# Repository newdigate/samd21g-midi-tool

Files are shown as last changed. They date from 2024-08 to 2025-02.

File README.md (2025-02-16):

# Midi Tool
[kicad](https://www.kicad.org/) design files for a general purpose midi dev board based on Arduino MKRZero 

* [samdg21](https://www.microchip.com/en-us/product/atsamd21g18) arm cortex m0 microcontroller
* DIN-5 midi input and output
* st7735 display (128x128 16bit)
* [PCF8523T](https://www.nxp.com/part/PCF8523T) realtime clock RTC
* socket for micro-SD card
* status LED
* SWD connection for programming
* PJ-320A connector for 2 foot-switches
* 5V POWER via USB
* 3V3 regulator
* 4-pin socket for neopixel strip
* Status LED

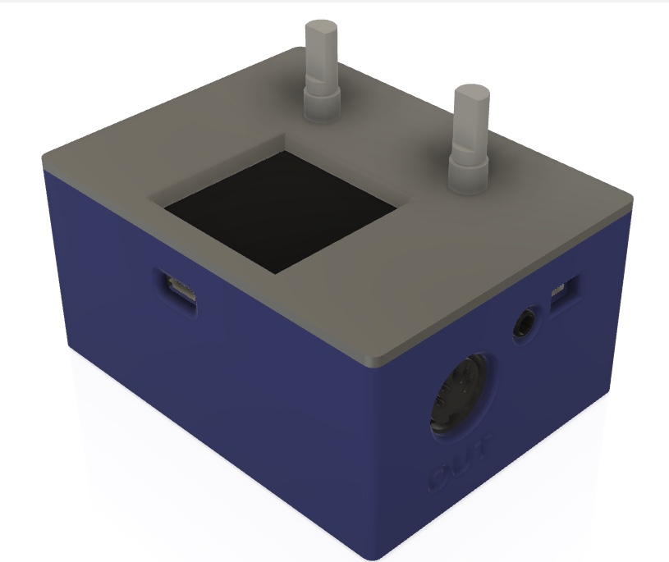
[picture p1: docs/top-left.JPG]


## Firmware
 * [samd21g-midi-tool-software](https://github.com/newdigate/samd21g-midi-tool-software)
   
## Kicad plugins
 * [JLCPCB](https://github.com/Bouni/kicad-jlcpcb-tools)
 * [Freerouting](https://github.com/freerouting/freerouting)

## Arduino libraries
* [PCF8523](https://github.com/SpellFoundry/PCF8523)
* [Adafruit-ST7735-Library](https://github.com/adafruit/Adafruit-ST7735-Library)
* [arduino_midi_library](https://github.com/FortySevenEffects/arduino_midi_library)

## sources / credits:
  * schematics and pcb design based on [MKRZERO Arduino](https://docs.arduino.cc/hardware/mkr-zero/)   
  * 3d models:
    * [PJ320A PJ320D 3.5mm JACK](https://grabcad.com/library/pj320a-pj320d-3-5mm-jack-1)
    * [SMD CR1220 Battery case](https://grabcad.com/library/smd-cr1220-battery-case-1)
  * footprints
    * [PJ-320A](https://github.com/nathanhborger/PJ-320A_KiCad_Library)

## images
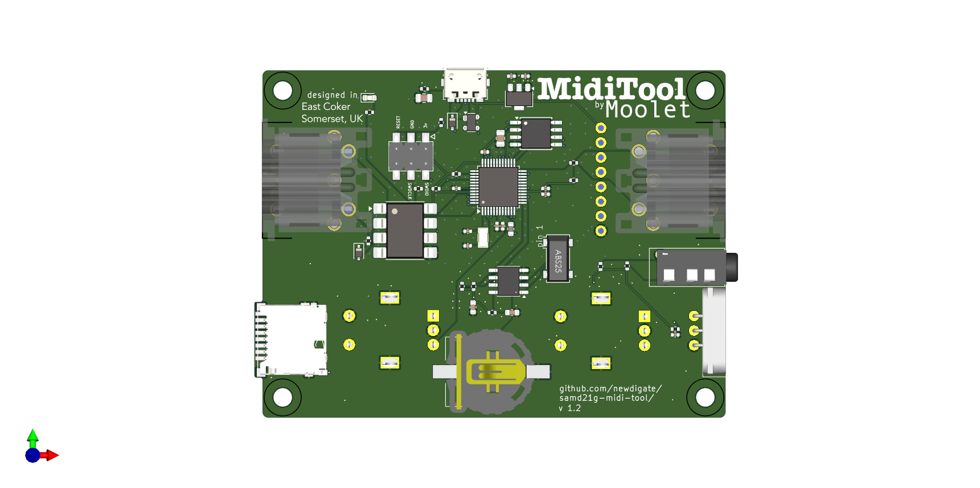
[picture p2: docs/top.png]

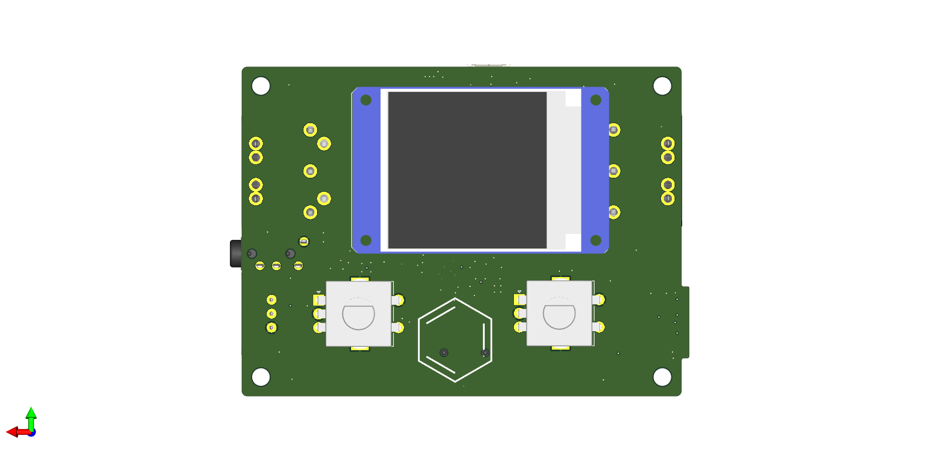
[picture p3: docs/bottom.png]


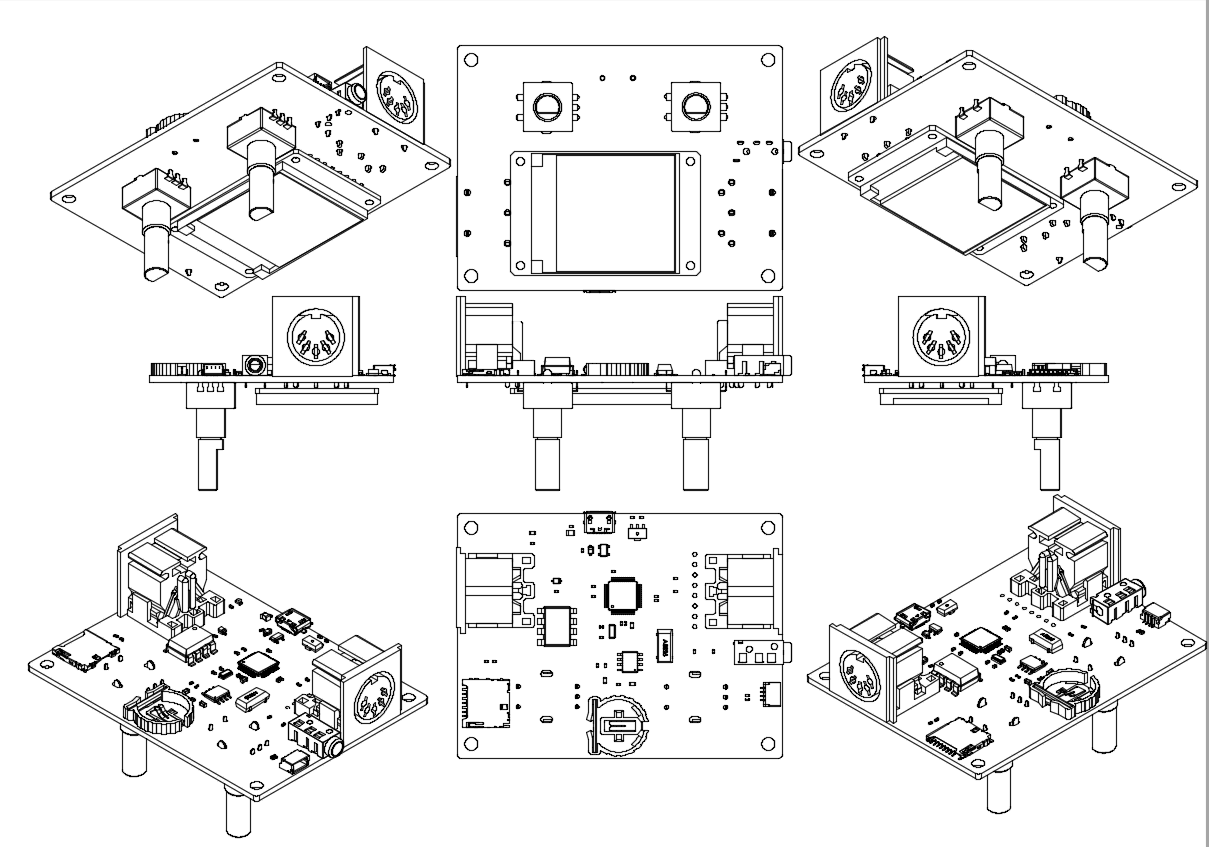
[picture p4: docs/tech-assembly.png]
tech-assembly


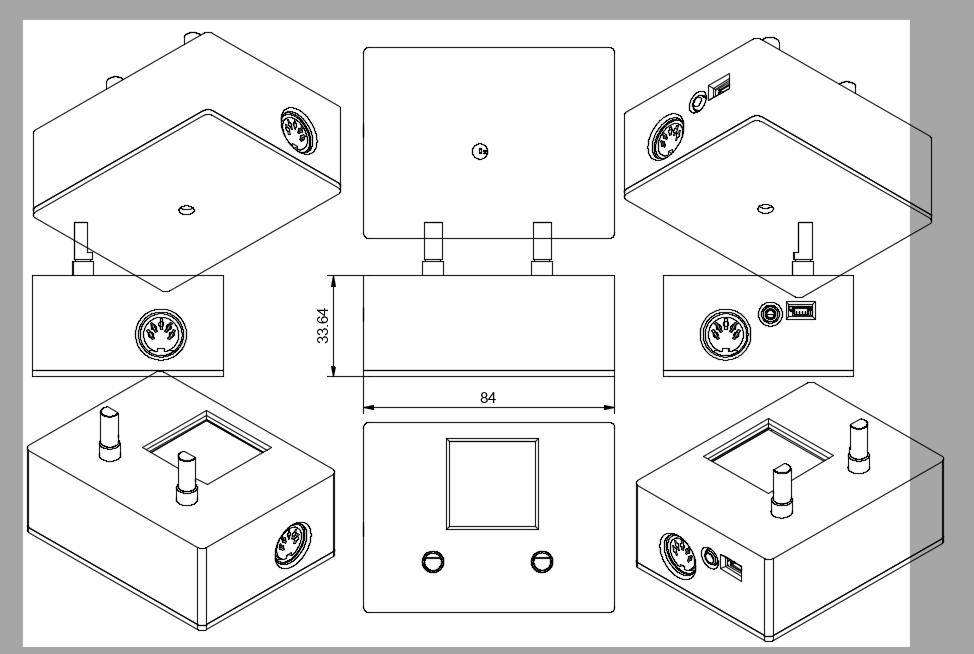
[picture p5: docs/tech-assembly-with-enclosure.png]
tech-assembly-with-enclosure


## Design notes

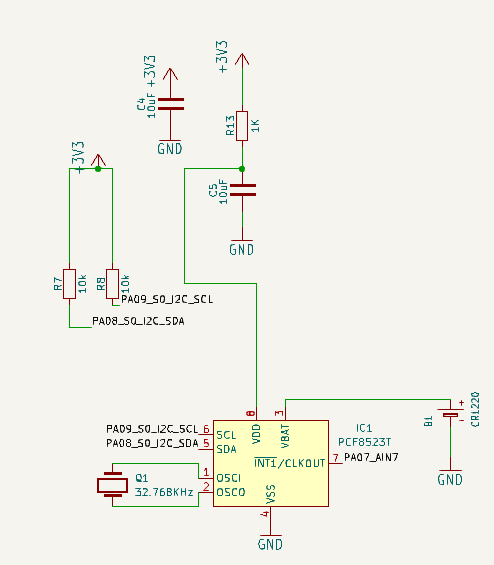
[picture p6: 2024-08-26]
docs/schematic2.png

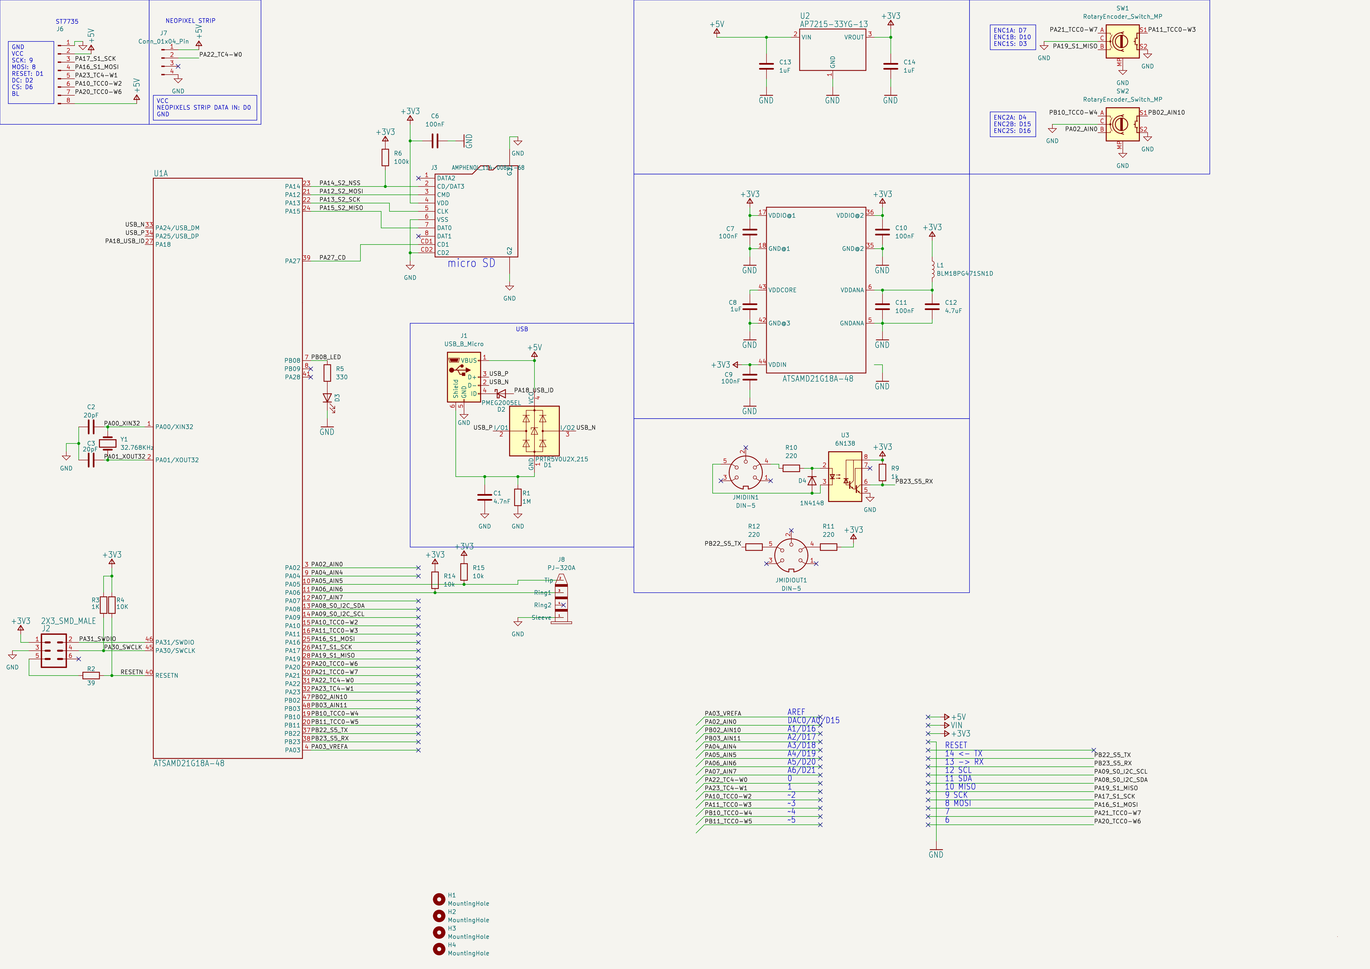
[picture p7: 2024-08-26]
docs/schematic1.png

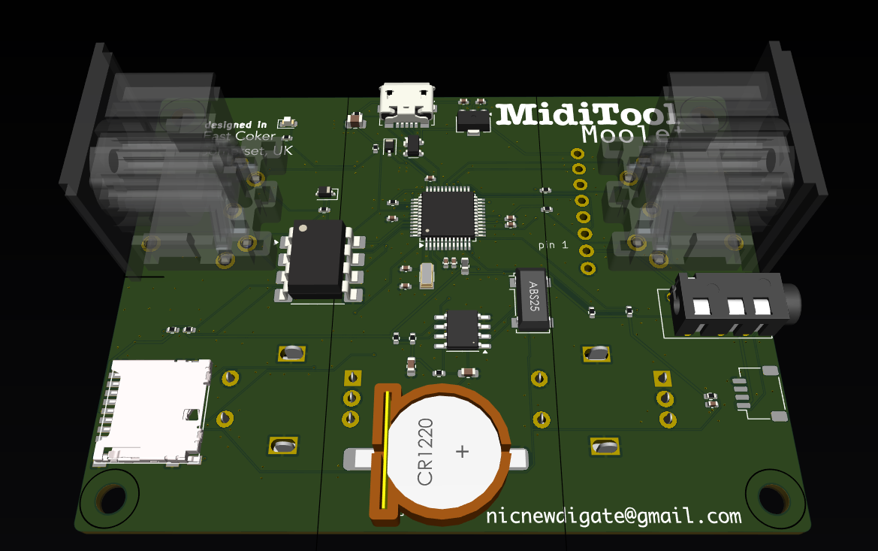
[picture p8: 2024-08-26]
docs/top-p.png

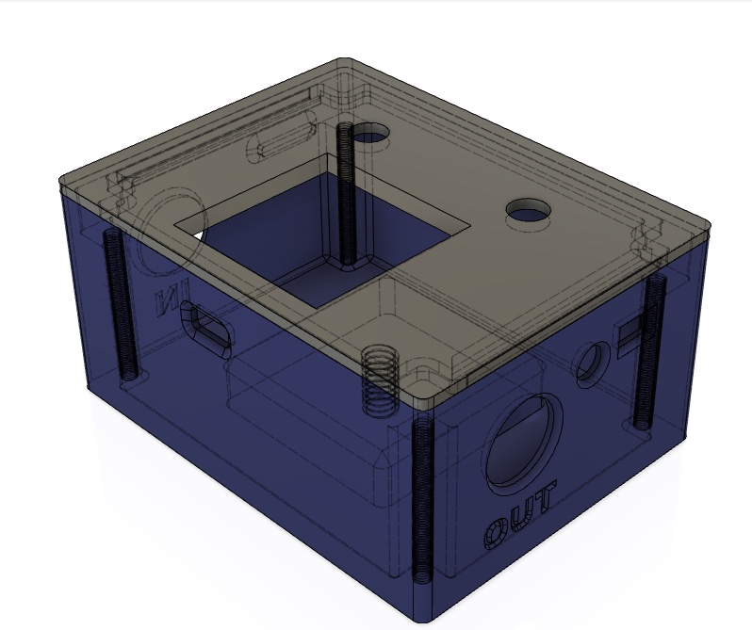
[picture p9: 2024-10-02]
docs/enclosure.JPG

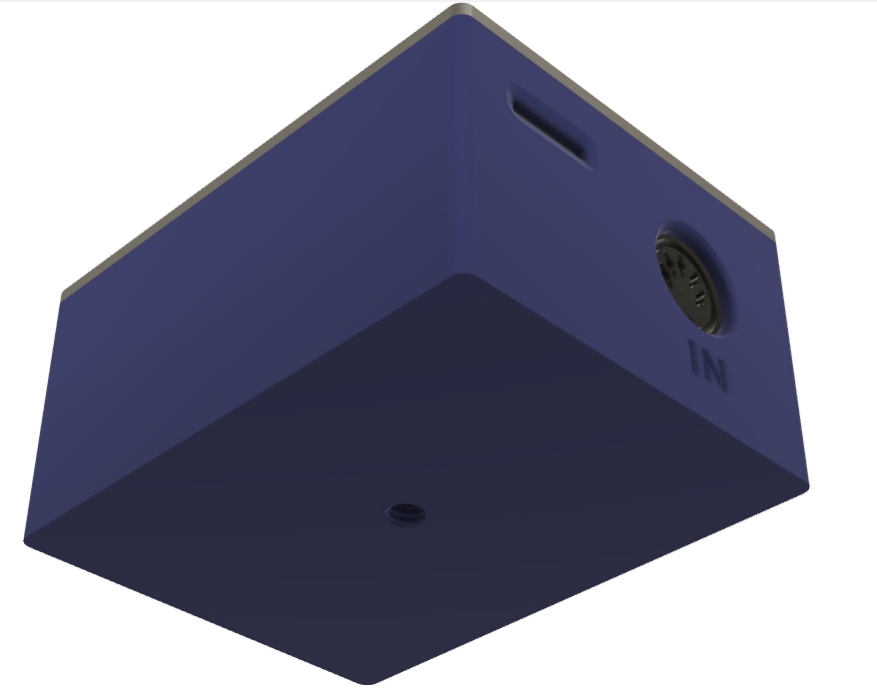
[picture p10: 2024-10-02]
docs/bottom-right.JPG

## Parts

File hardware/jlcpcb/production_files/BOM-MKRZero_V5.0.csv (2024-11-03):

Comment | Designator | Footprint | LCSC
1K | R13,R3 | R_0402_1005Metric | C11702
PRTR5V0U2X,215 | D1 | SOT-143 | C12333
USB_B_Micro | J1 | USB_Micro-B_Molex_47346-0001 | C132560
.1uF | C15 | C_0805_2012Metric | C150376
100nF | C10,C11,C16,C6,C7,C9 | C_0402_1005Metric | C1525
20pF | C2,C3 | C_0402_1005Metric | C1554
4.7nF | C1 | C_0805_2012Metric | C1744
470 | R9 | R_0805_2012Metric | C17710
47 | R11,R12 | R_0805_2012Metric | C17714
PMEG2005EL | D2 | D_SOD-323 | C179428
32.768KHz | Q1 | Crystal_SMD_Abracon_ABS25-4Pin_8.0x3.8mm | C179637
6N138 | U3 | SOP-8_6.605x9.655mm_P2.54mm | C188666
10uF | C4,C5 | C_0603_1608Metric | C19702
DIN-5 | JMIDIIN1,JMIDIOUT1 | Deltron-671-0501-5 | C20611696
1N4148 | D4 | D_SOD-323 | C2128
LED | D3 | LED_0603_1608Metric | C2286
4.7uF | C12 | C_0402_1005Metric | C23733
220 | R10 | R_0402_1005Metric | C25091
10k | R14,R15,R5 | R_0402_1005Metric | C25104
39 | R2 | R_0402_1005Metric | C25109
100k | R6 | R_0402_1005Metric | C25741
10K | R4,R7,R8 | R_0402_1005Metric | C25744
1M | R1 | R_0402_1005Metric | C26083
PCF8523T | IC1 | SOP-8_3.9x4.9mm_P1.27mm | C2651516
AMPHENOL_114-00841-68 | J3 | AMPHENOL_114-00841-68 | C2848817
PJ-320A | J8 | PJ-320A | C2884984
32.768KHz | Y1 | Crystal_SMD_3215-2Pin_3.2x1.5mm | C32346
2X3_SMD_MALE | J2 | 2X3_SMT | C3294461
RotaryEncoder_Switch_MP | SW1 | RotaryEncoder_Alps_EC11E-Switch_Vertical_H20mm | C361165
AP7215-33YG-13 | U2 | SOT-89-3 | C460367
1uF | C13,C14,C8 | C_0402_1005Metric | C52923
ATSAMD21G18A-48 | U1 | TQFP-48_7x7mm_P0.5mm | C78624
BLM18PG471SN1D | L1 | L_0603_1608Metric | C97853
Conn_01x03_Pin | J7 | MG03254F-RA
Conn_01x08_Pin | J6 | ST7735
RotaryEncoder_Switch_MP | SW2 | RotaryEncoder_Alps_EC11E-Switch_Vertical_H20mm
CR1220-2 | IC2 | CR12202
W25Q128JVS | U4 | SOIC-8W_5.3x5.3mm_P1.27mm

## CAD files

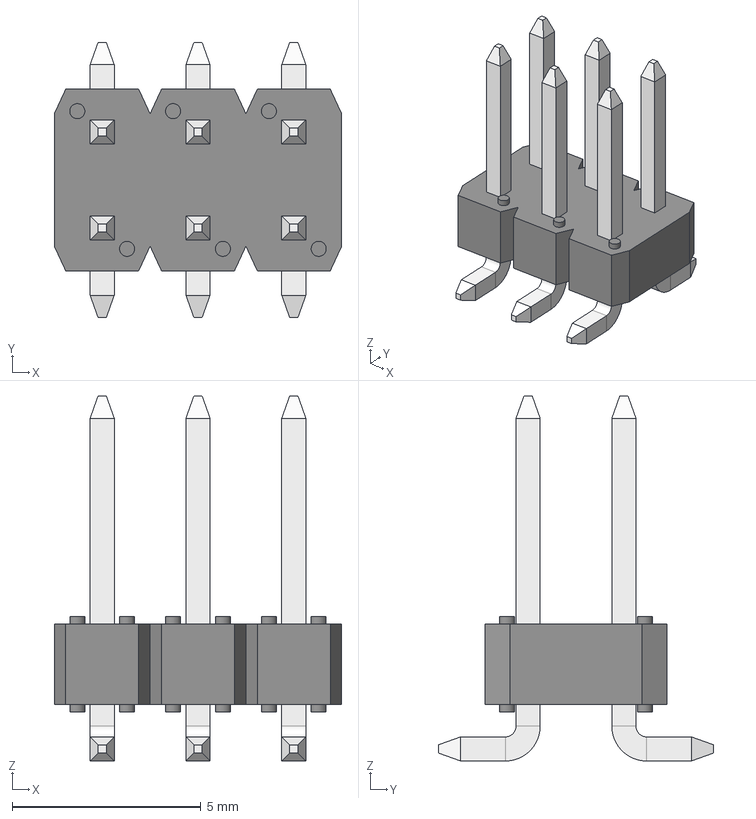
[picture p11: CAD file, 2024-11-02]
hardware/3d/Header 3x2 vert 0.1 inch pitch smt.step
7.62 x 7.29 x 9.68 mm

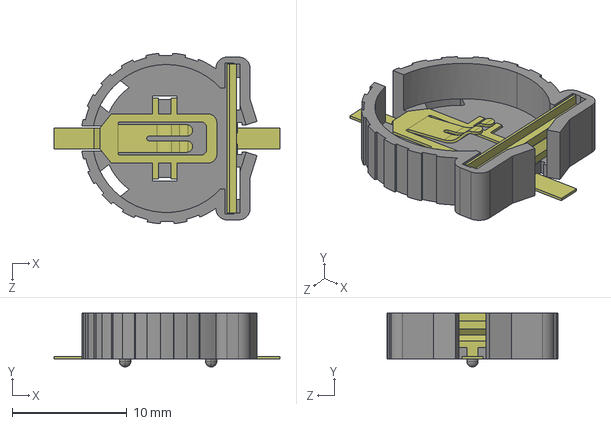
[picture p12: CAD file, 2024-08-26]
hardware/3d/CR1220-2.stp
19.7 x 4.70 x 14.9 mm

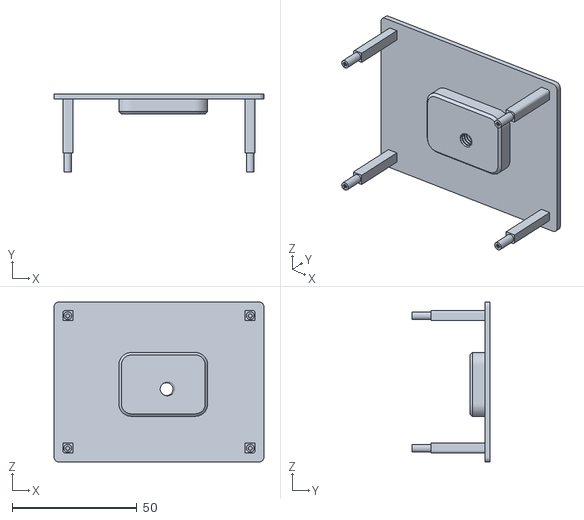
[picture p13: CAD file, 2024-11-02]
hardware/base.stl
84.0 x 31.0 x 64.0

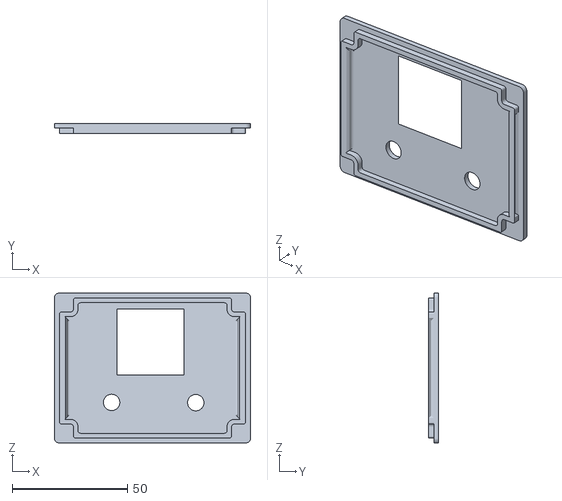
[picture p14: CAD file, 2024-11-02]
hardware/EnclosureLid.stl
85.0 x 4.40 x 65.0

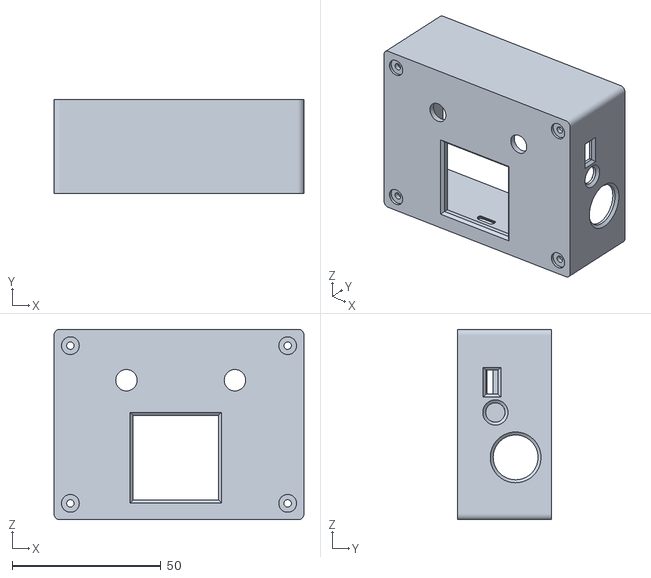
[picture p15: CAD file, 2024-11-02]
hardware/body2.stl
84.0 x 31.6 x 64.0

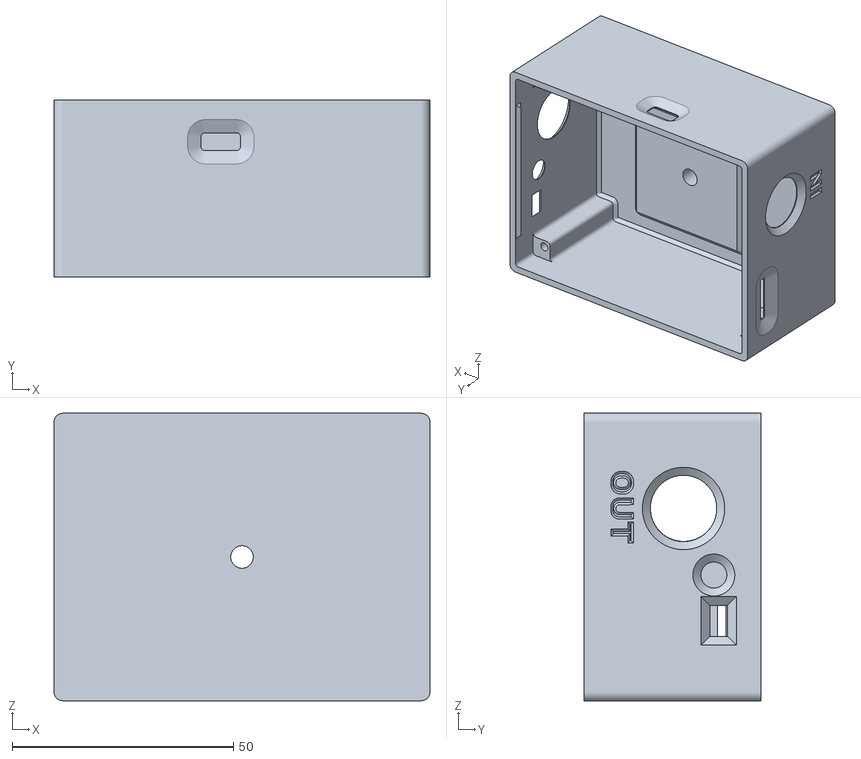
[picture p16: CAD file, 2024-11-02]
hardware/EnclosureBase.stl
85.0 x 40.0 x 65.0

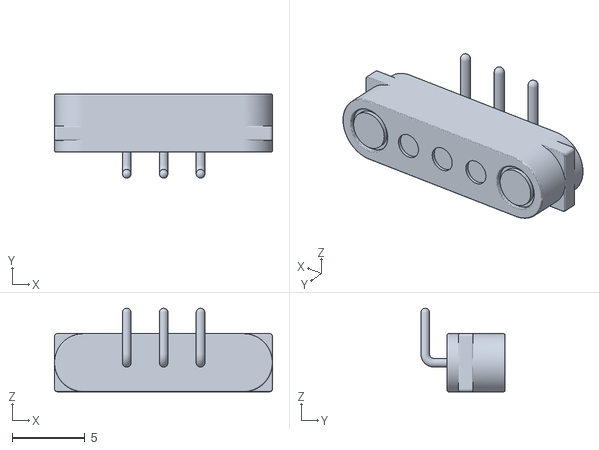
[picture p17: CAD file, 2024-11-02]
hardware/MG03254F-RA.stl
15.0 x 5.80 x 5.75

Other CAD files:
hardware/Lid.step
hardware/MG03254F-RA v1.step
hardware/enclosure.f3z

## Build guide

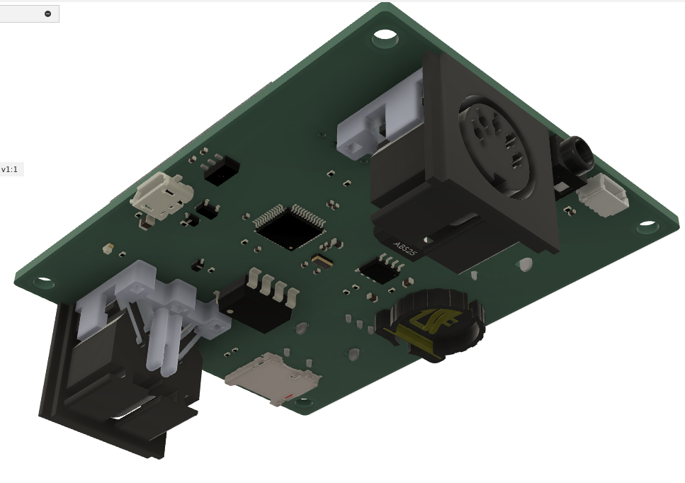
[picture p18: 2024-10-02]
docs/assembly-bottom.png

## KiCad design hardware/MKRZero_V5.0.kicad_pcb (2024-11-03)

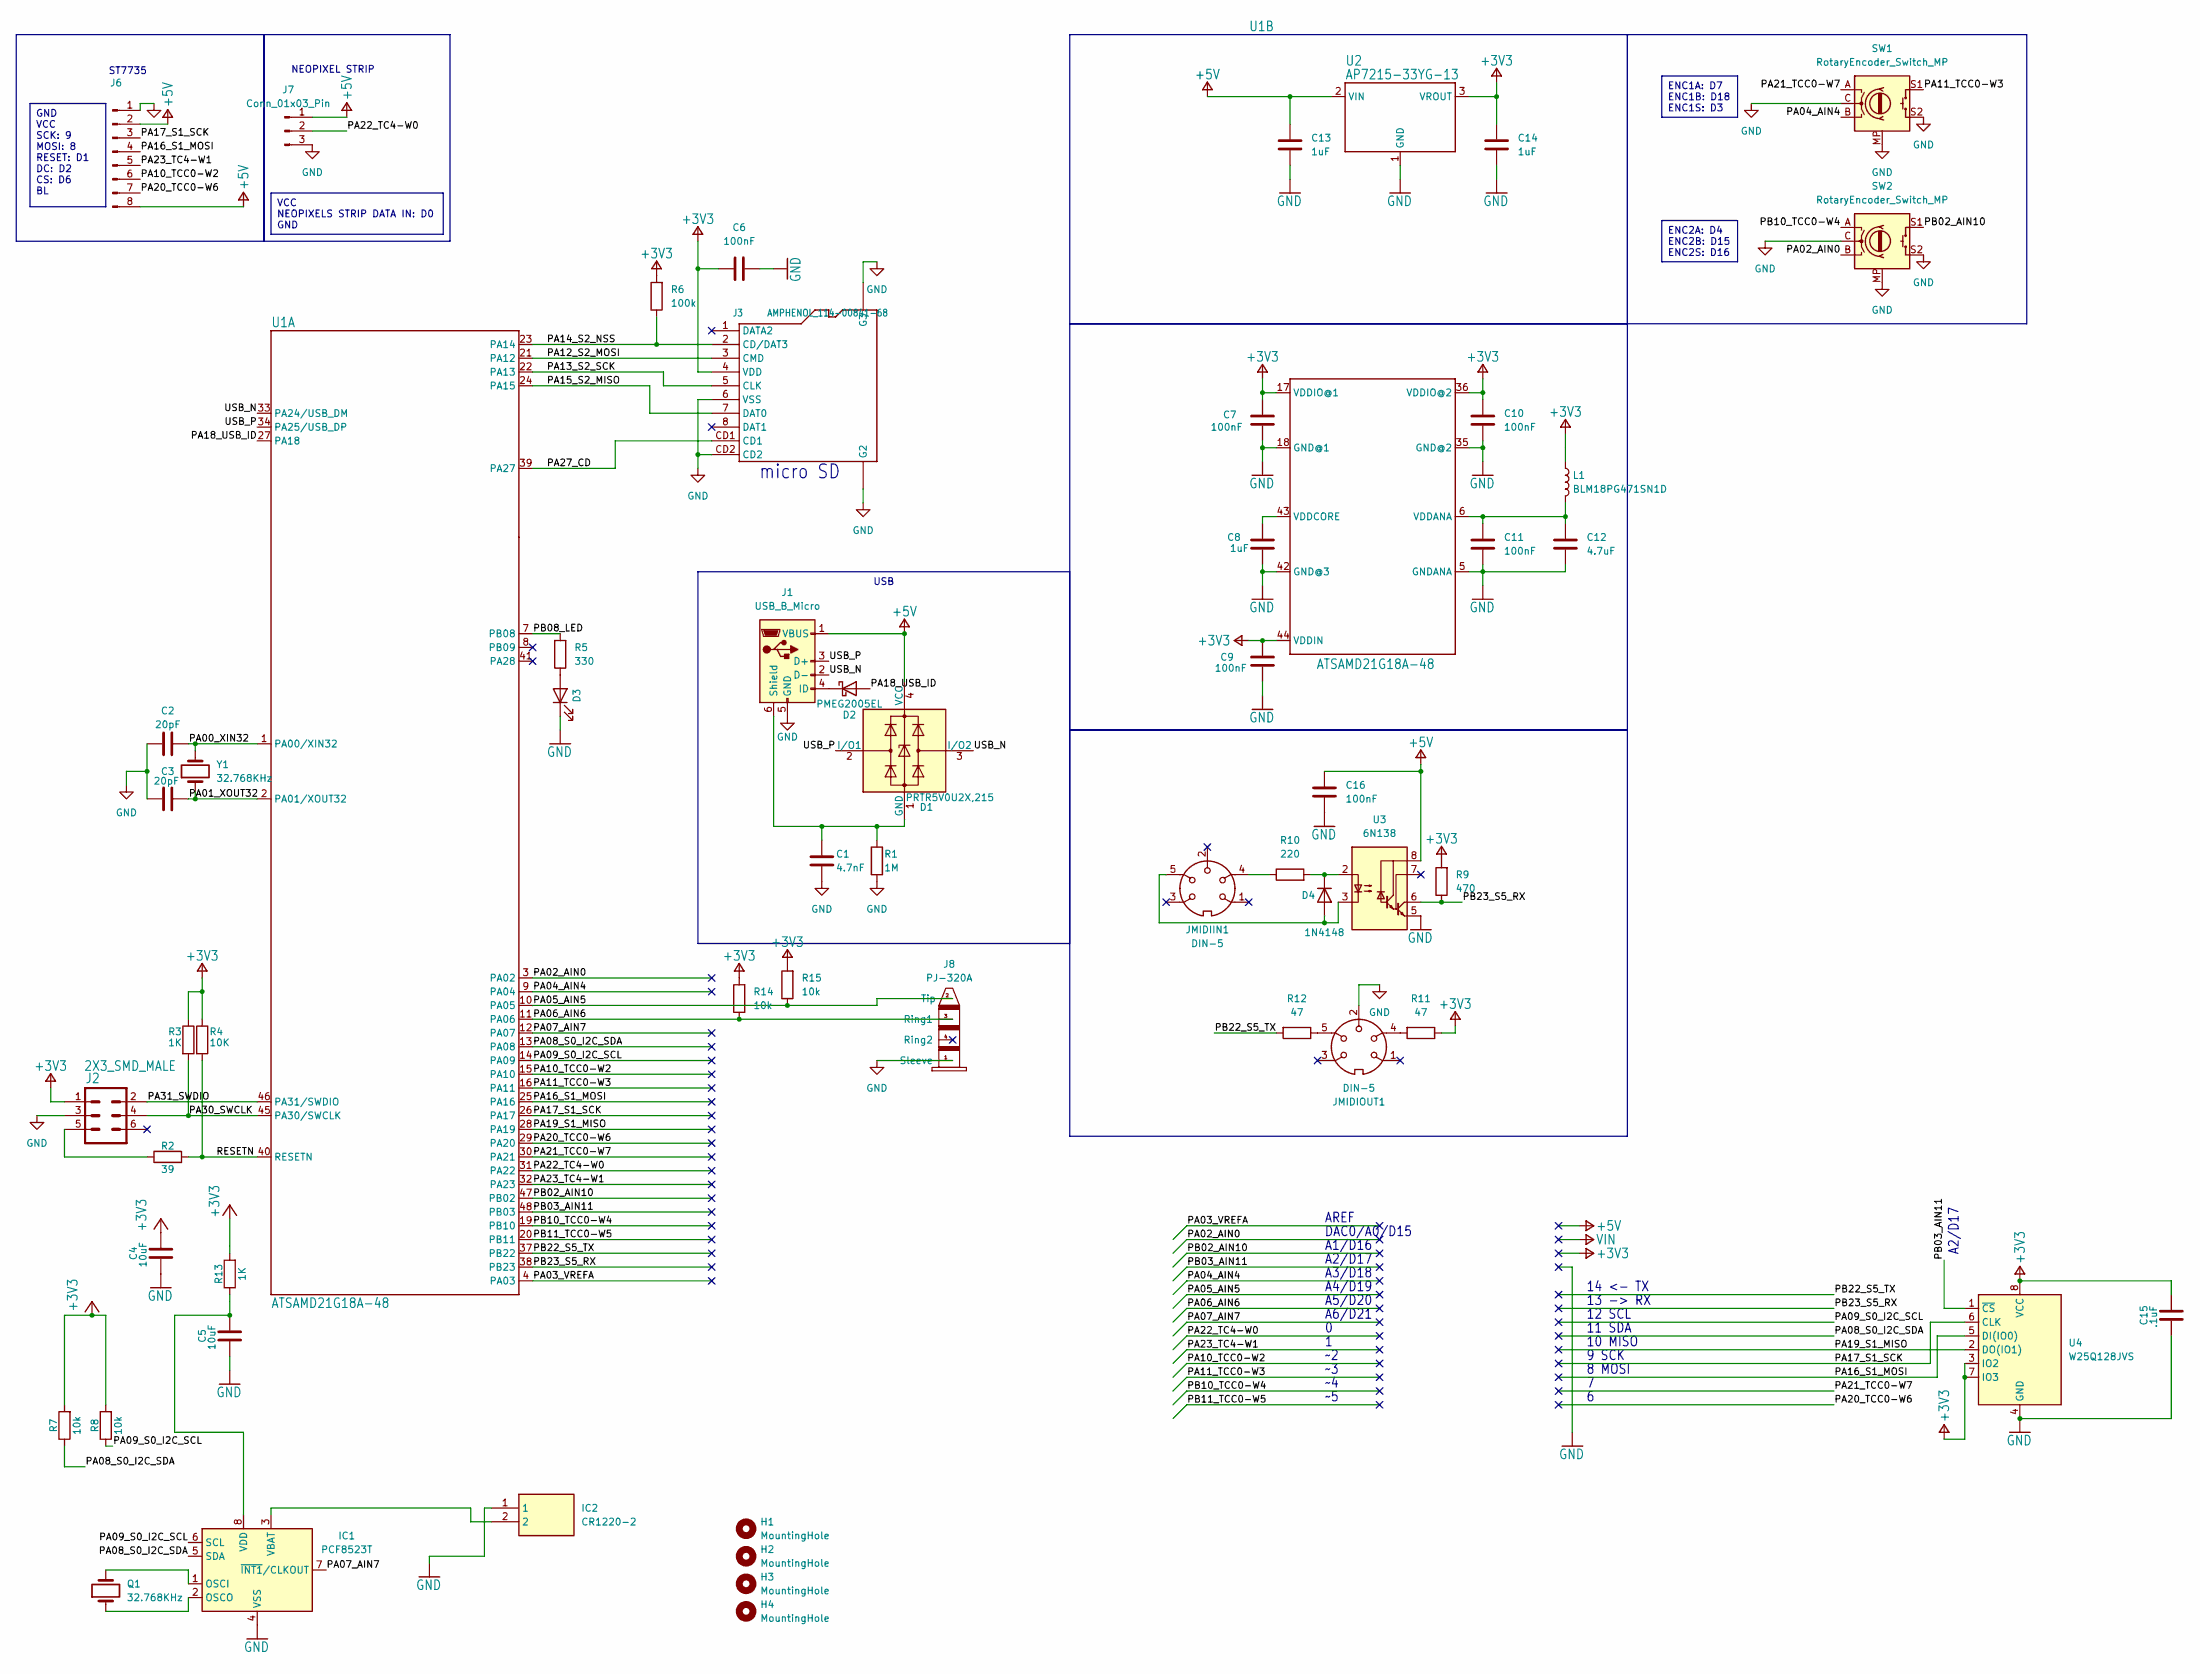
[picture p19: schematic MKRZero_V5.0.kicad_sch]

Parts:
C1: 4.7nF; C_0805_2012Metric; LCSC C1744
C2, C3: 20pF; C_0402_1005Metric; LCSC C1554
C4, C5: 10uF; C_0603_1608Metric; LCSC C19702
C6, C7, C9, C10, C11, C16: 100nF; C_0402_1005Metric; LCSC C1525
C8, C13, C14: 1uF; C_0402_1005Metric; LCSC C52923
C12: 4.7uF; C_0402_1005Metric; LCSC C23733
C15: .1uF; C_0805_2012Metric; LCSC C150376
D1: PRTR5V0U2X,215; SOT-143; LCSC C12333
D2: PMEG2005EL; D_SOD-323; LCSC C179428
D3: LED; LED_0603_1608Metric; LCSC C2286
D4: 1N4148; D_SOD-323; LCSC C2128
H1, H2, H3, H4: MountingHole; MountingHole_3.2mm_M3
IC1: PCF8523T; SOP-8_3.9x4.9mm_P1.27mm; LCSC C2651516
IC2: CR1220-2; CR12202; Manufacturer_Part_Number CR1220-2
J1: USB_B_Micro; USB_Micro-B_Molex_47346-0001; LCSC C132560
J2: 2X3_SMD_MALE; 2X3_SMT; LCSC C3294461
J3: AMPHENOL_114-00841-68; LCSC C2848817
J6: Conn_01x08_Pin; ST7735
J7: Conn_01x03_Pin; MG03254F-RA
J8: PJ-320A; LCSC C2884984
JMIDIIN1: DIN-5; Deltron-671-0501-5; LCSC C20611696
JMIDIOUT1: DIN-5; Deltron-671-0501-5; LCSC C20611696
L1: BLM18PG471SN1D; L_0603_1608Metric; LCSC C97853
Q1: 32.768KHz; Crystal_SMD_Abracon_ABS25-4Pin_8.0x3.8mm; LCSC C179637
R1: 1M; R_0402_1005Metric; LCSC C26083
R2: 39; R_0402_1005Metric; LCSC C25109
R3, R13: 1K; R_0402_1005Metric; LCSC C11702
R4: 10K; R_0402_1005Metric; LCSC C25744
R5: 330; R_0402_1005Metric; LCSC C25104
R6: 100k; R_0402_1005Metric; LCSC C25741
R7, R8: 10k; R_0402_1005Metric; LCSC C25744
R9: 470; R_0805_2012Metric; LCSC C17710
R10: 220; R_0402_1005Metric; LCSC C25091
R11, R12: 47; R_0805_2012Metric; LCSC C17714
R14, R15: 10k; R_0402_1005Metric; LCSC C25104
SW1: RotaryEncoder_Switch_MP; RotaryEncoder_Alps_EC11E-Switch_Vertical_H20mm; LCSC C361165
SW2: RotaryEncoder_Switch_MP; RotaryEncoder_Alps_EC11E-Switch_Vertical_H20mm
U1: ATSAMD21G18A-48; TQFP-48_7x7mm_P0.5mm; LCSC C78624
U2: AP7215-33YG-13; SOT-89-3; LCSC C460367
U3: 6N138; SOP-8_6.605x9.655mm_P2.54mm; LCSC C188666
U4: W25Q128JVS; SOIC-8W_5.3x5.3mm_P1.27mm
Y1: 32.768KHz; Crystal_SMD_3215-2Pin_3.2x1.5mm; LCSC C32346

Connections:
+3V3: C4.2, C6.1, C7.1, C9.1, C10.2, C14.2, C15.2, J2.1, J3.4 (VDD), L1.1, R3.1, R4.1, R6.2, R7.2, R8.2, R9.2, R11.1, R13.2, R14.2, R15.2, U1.17 (VDDIO@1), U1.36 (VDDIO@2), U1.44 (VDDIN), U2.3 (VROUT), U4.3 (IO2), U4.7 (IO3), U4.8 (VCC)
+5V: C13.2, C16.2, D1.4 (VCC), J1.1 (VBUS), J6.2, J6.8, J7.1, U2.2 (VIN), U3.8 (VCC)
/PA00_XIN32: C2.2, U1.1 (PA00/XIN32), Y1.2
/PA01_XOUT32: C3.2, U1.2 (PA01/XOUT32), Y1.1
/PA02_AIN0: SW2.B, U1.3 (PA02)
/PA03_VREFA: U1.4 (PA03)
/PA04_AIN4: SW1.B, U1.9 (PA04)
/PA05_AIN5: J8.2 (Tip), R15.1, U1.10 (PA05)
/PA06_AIN6: J8.3 (Ring1), R14.1, U1.11 (PA06)
/PA07_AIN7: IC1.7 (~INT1/CLKOUT), U1.12 (PA07)
/PA08_S0_I2C_SDA: IC1.5 (SDA), R7.1, U1.13 (PA08)
/PA09_S0_I2C_SCL: IC1.6 (SCL), R8.1, U1.14 (PA09)
/PA10_TCC0-W2: J6.6, U1.15 (PA10)
/PA11_TCC0-W3: SW1.S1, U1.16 (PA11)
/PA12_S2_MOSI: J3.3 (CMD), U1.21 (PA12)
/PA13_S2_SCK: J3.5 (CLK), U1.22 (PA13)
/PA14_S2_NSS: J3.2 (CD/DAT3), R6.1, U1.23 (PA14)
/PA15_S2_MISO: J3.7 (DAT0), U1.24 (PA15)
/PA16_S1_MOSI: J6.4, U1.25 (PA16), U4.5 (DI(IO0))
/PA17_S1_SCK: J6.3, U1.26 (PA17), U4.6 (CLK)
/PA18_USB_ID: D2.2 (A), U1.27 (PA18)
/PA19_S1_MISO: U1.28 (PA19), U4.2 (DO(IO1))
/PA20_TCC0-W6: J6.7, U1.29 (PA20)
/PA21_TCC0-W7: SW1.A, U1.30 (PA21)
/PA22_TC4-W0: J7.2, U1.31 (PA22)
/PA23_TC4-W1: J6.5, U1.32 (PA23)
/PA27_CD: J3.CD1, U1.39 (PA27)
/PA30_SWCLK: J2.4, R3.2, U1.45 (PA30/SWCLK)
/PA31_SWDIO: J2.2, U1.46 (PA31/SWDIO)
/PB02_AIN10: SW2.S1, U1.47 (PB02)
/PB03_AIN11: U1.48 (PB03), U4.1 (~CS)
/PB08_LED: R5.2, U1.7 (PB08)
/PB10_TCC0-W4: SW2.A, U1.19 (PB10)
/PB11_TCC0-W5: U1.20 (PB11)
/PB22_S5_TX: R12.2, U1.37 (PB22)
/PB23_S5_RX: R9.1, U1.38 (PB23), U3.6 (VO2)
/RESETN: R2.2, R4.2, U1.40 (RESETN)
/USB_N: D1.3 (I/O2), J1.2 (D-), U1.33 (PA24/USB_DM)
/USB_P: D1.2 (I/O1), J1.3 (D+), U1.34 (PA25/USB_DP)
GND: C1.2, C2.1, C3.1, C4.1, C5.1, C6.2, C7.2, C8.2, C9.2, C10.1, C11.2, C12.2, C13.1, C14.1, C15.1, C16.1, D3.1 (K), IC1.4 (VSS), IC2.1, J1.5 (GND), J2.3, J3.6 (VSS), J3.CD2, J3.SH1 (G3), J3.SH2 (G3), J3.SH3 (G2), J3.SH4 (G2), J6.1, J7.3, J8.1 (Sleeve), JMIDIOUT1.2, R1.2, SW1.C, SW1.MP, SW1.S2, SW2.C, SW2.MP, SW2.S2, U1.5 (GNDANA), U1.18 (GND@1), U1.35 (GND@2), U1.42 (GND@3), U2.1 (GND), U3.5 (GND), U4.4 (GND)
unnamed: C1.1, D1.1 (GND), J1.6 (Shield), R1.1
unnamed: D2.1 (K), J1.4 (ID)
unnamed: D3.2 (A), R5.1
unnamed: D4.2 (A), JMIDIIN1.5, U3.3 (C2)
unnamed: D4.1 (K), R10.2, U3.2 (C1)
unnamed: IC1.1 (OSCI), Q1.4 (e)
unnamed: IC1.2 (OSCO), Q1.1
unnamed: IC1.3 (VBAT), IC2.2
unnamed: C5.2, IC1.8 (VDD), R13.1
unnamed: J2.5, R2.1
unnamed: JMIDIIN1.4, R10.1
unnamed: JMIDIOUT1.4, R11.2
unnamed: JMIDIOUT1.5, R12.1
unnamed: C11.1, C12.1, L1.2, U1.6 (VDDANA)
unnamed: C8.1, U1.43 (VDDCORE)

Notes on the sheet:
GND VCC SCK: 9 MOSI: 8 RESET: D1 DC: D2 CS: D6 BL
VCC NEOPIXELS STRIP DATA IN: D0 GND
ENC1A: D7 ENC1B: D18 ENC1S: D3
ENC2A: D4 ENC2B: D15 ENC2S: D16
A5/D20
A6/D21
11 SDA
13 -> RX
12 SCL
A2/D17
14 <- TX
NEOPIXEL STRIP
ST7735
8 MOSI
A1/D16
AREF
A4/D19
10 MISO
USB
9 SCK
A3/D18
DAC0/A0/D15
micro SD

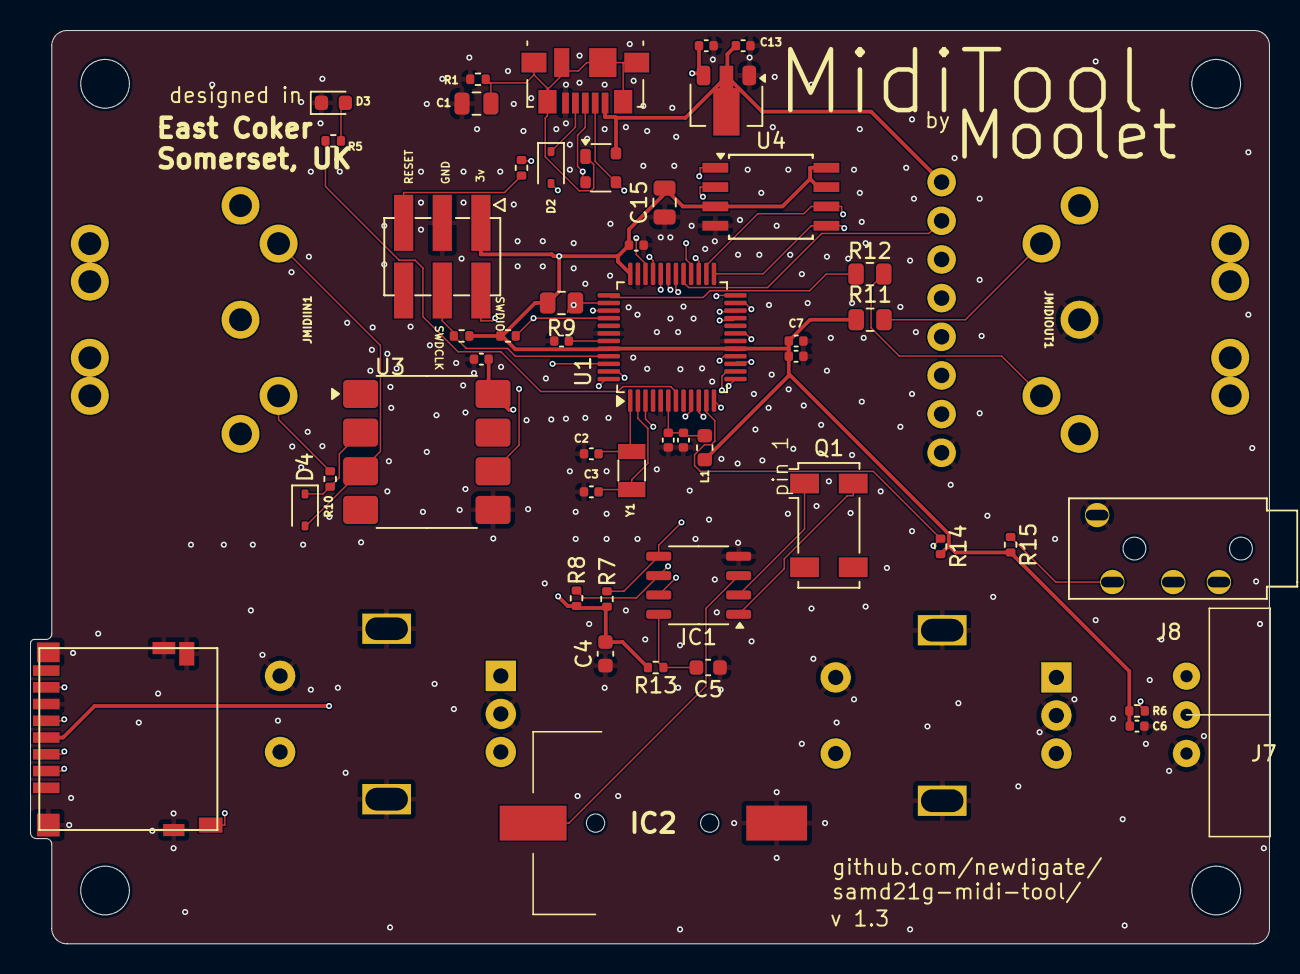
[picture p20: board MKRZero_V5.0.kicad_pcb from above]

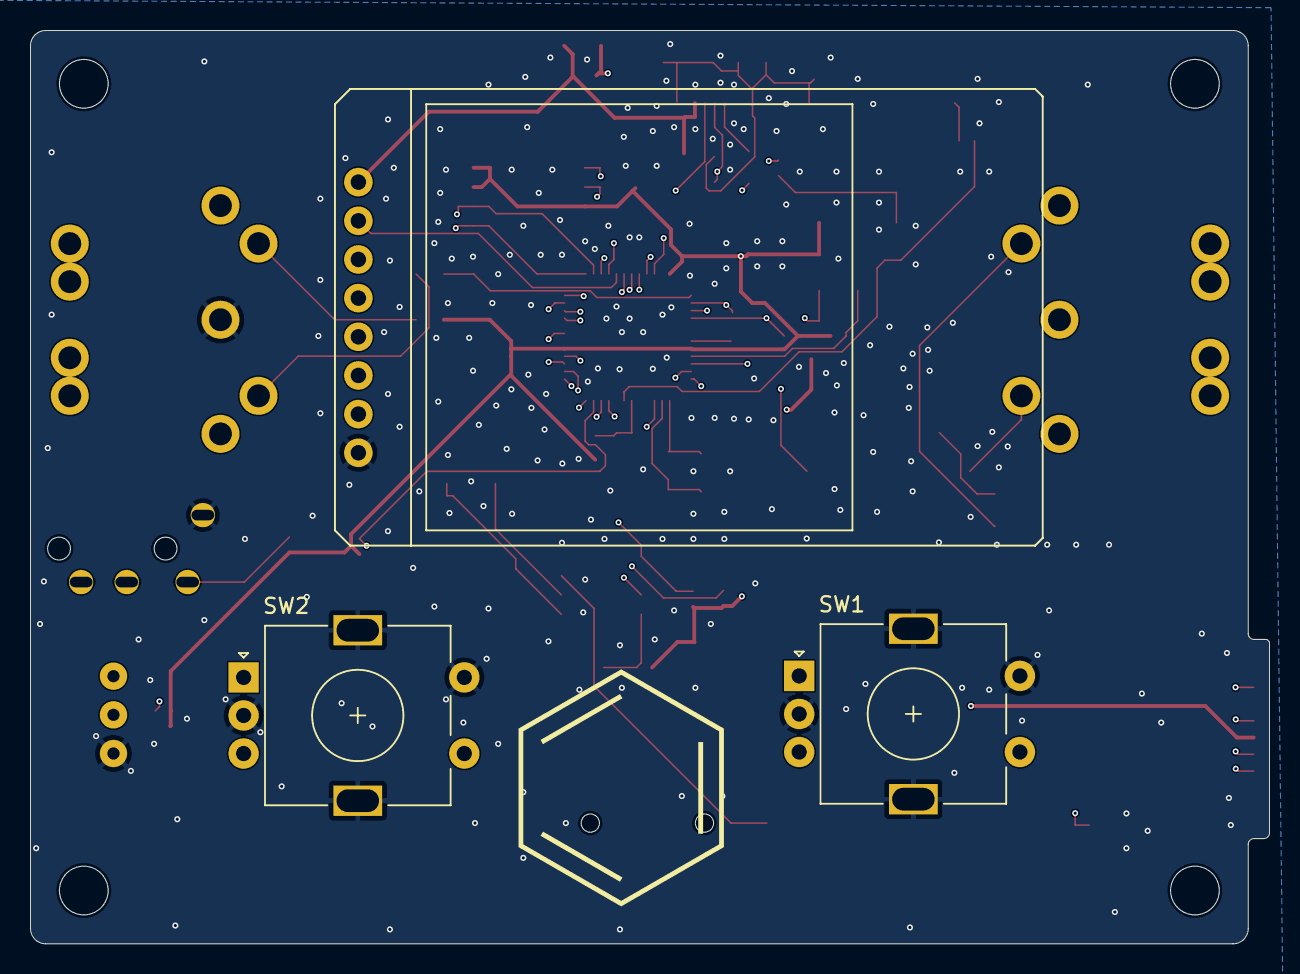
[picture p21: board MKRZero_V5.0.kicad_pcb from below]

Board: 4 copper layers, 81.4 x 60.0 mm, 58 parts (3 on the bottom side), 53 nets.

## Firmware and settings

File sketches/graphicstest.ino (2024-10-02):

/**************************************************************************
  This is a library for several Adafruit displays based on ST77* drivers.

  Works with the Adafruit 1.8" TFT Breakout w/SD card
    ----> http://www.adafruit.com/products/358
  The 1.8" TFT shield
    ----> https://www.adafruit.com/product/802
  The 1.44" TFT breakout
    ----> https://www.adafruit.com/product/2088
  The 1.14" TFT breakout
  ----> https://www.adafruit.com/product/4383
  The 1.3" TFT breakout
  ----> https://www.adafruit.com/product/4313
  The 1.54" TFT breakout
    ----> https://www.adafruit.com/product/3787
  The 1.69" TFT breakout
    ----> https://www.adafruit.com/product/5206
  The 2.0" TFT breakout
    ----> https://www.adafruit.com/product/4311
  as well as Adafruit raw 1.8" TFT display
    ----> http://www.adafruit.com/products/618

  Check out the links above for our tutorials and wiring diagrams.
  These displays use SPI to communicate, 4 or 5 pins are required to
  interface (RST is optional).

  Adafruit invests time and resources providing this open source code,
  please support Adafruit and open-source hardware by purchasing
  products from Adafruit!

  Written by Limor Fried/Ladyada for Adafruit Industries.
  MIT license, all text above must be included in any redistribution
 **************************************************************************/

#include <Adafruit_GFX.h>    // Core graphics library
#include <Adafruit_ST7735.h> // Hardware-specific library for ST7735
#include <Adafruit_ST7789.h> // Hardware-specific library for ST7789
#include <SPI.h>


#define TFT_CS        6
#define TFT_RST        1 // Or set to -1 and connect to Arduino RESET pin
#define TFT_DC         2

// OPTION 1 (recommended) is to use the HARDWARE SPI pins, which are unique
// to each board and not reassignable. For Arduino Uno: MOSI = pin 11 and
// SCLK = pin 13. This is the fastest mode of operation and is required if
// using the breakout board's microSD card.

// For 1.44" and 1.8" TFT with ST7735 use:
Adafruit_ST7735 tft = Adafruit_ST7735(TFT_CS, TFT_DC, TFT_RST);

// For 1.14", 1.3", 1.54", 1.69", and 2.0" TFT with ST7789:
//Adafruit_ST7789 tft = Adafruit_ST7789(TFT_CS, TFT_DC, TFT_RST);


// OPTION 2 lets you interface the display using ANY TWO or THREE PINS,
// tradeoff being that performance is not as fast as hardware SPI above.
//#define TFT_MOSI 11  // Data out
//#define TFT_SCLK 13  // Clock out

// For ST7735-based displays, we will use this call
//Adafruit_ST7735 tft = Adafruit_ST7735(TFT_CS, TFT_DC, TFT_MOSI, TFT_SCLK, TFT_RST);

// OR for the ST7789-based displays, we will use this call
//Adafruit_ST7789 tft = Adafruit_ST7789(TFT_CS, TFT_DC, TFT_MOSI, TFT_SCLK, TFT_RST);


float p = 3.1415926;

void setup(void) {
  Serial.begin(9600);
  while(!Serial);

  Serial.print(F("Hello! ST77xx TFT Test"));

  // Use this initializer if using a 1.8" TFT screen:
  //tft.initR(INITR_BLACKTAB);      // Init ST7735S chip, black tab

  // OR use this initializer if using a 1.8" TFT screen with offset such as WaveShare:
  // tft.initR(INITR_GREENTAB);      // Init ST7735S chip, green tab

  // OR use this initializer (uncomment) if using a 1.44" TFT:
  tft.initR(INITR_144GREENTAB); // Init ST7735R chip, green tab

  // OR use this initializer (uncomment) if using a 0.96" 160x80 TFT:
  //tft.initR(INITR_MINI160x80);  // Init ST7735S mini display
  // OR use this initializer (uncomment) if using a 0.96" 160x80 TFT with 
  // plug-in FPC (if you see the display is inverted!)
  //tft.initR(INITR_MINI160x80_PLUGIN);  // Init ST7735S mini display

  // OR use this initializer (uncomment) if using a 1.3" or 1.54" 240x240 TFT:
  //tft.init(240, 240);           // Init ST7789 240x240

  // OR use this initializer (uncomment) if using a 1.69" 280x240 TFT:
  //tft.init(240, 280);           // Init ST7789 280x240

  // OR use this initializer (uncomment) if using a 2.0" 320x240 TFT:
  //tft.init(240, 320);           // Init ST7789 320x240

  // OR use this initializer (uncomment) if using a 1.14" 240x135 TFT:
  //tft.init(135, 240);           // Init ST7789 240x135
  
  // OR use this initializer (uncomment) if using a 1.47" 172x320 TFT:
  //tft.init(172, 320);           // Init ST7789 172x320

  // SPI speed defaults to SPI_DEFAULT_FREQ defined in the library, you can override it here
  // Note that speed allowable depends on chip and quality of wiring, if you go too fast, you
  // may end up with a black screen some times, or all the time.
  //tft.setSPISpeed(40000000);

  Serial.println(F("Initialized"));

  uint16_t time = millis();
  tft.fillScreen(ST77XX_BLACK);
  time = millis() - time;

  Serial.println(time, DEC);
  delay(500);

  // large block of text
  tft.fillScreen(ST77XX_BLACK);
  testdrawtext("Lorem ipsum dolor sit amet, consectetur adipiscing elit. Curabitur adipiscing ante sed nibh tincidunt feugiat. Maecenas enim massa, fringilla sed malesuada et, malesuada sit amet turpis. Sed porttitor neque ut ante pretium vitae malesuada nunc bibendum. Nullam aliquet ultrices massa eu hendrerit. Ut sed nisi lorem. In vestibulum purus a tortor imperdiet posuere. ", ST77XX_WHITE);
  delay(1000);

  // tft print function!
  tftPrintTest();
  delay(4000);

  // a single pixel
  tft.drawPixel(tft.width()/2, tft.height()/2, ST77XX_GREEN);
  delay(500);

  // line draw test
  testlines(ST77XX_YELLOW);
  delay(500);

  // optimized lines
  testfastlines(ST77XX_RED, ST77XX_BLUE);
  delay(500);

  testdrawrects(ST77XX_GREEN);
  delay(500);

  testfillrects(ST77XX_YELLOW, ST77XX_MAGENTA);
  delay(500);

  tft.fillScreen(ST77XX_BLACK);
  testfillcircles(10, ST77XX_BLUE);
  testdrawcircles(10, ST77XX_WHITE);
  delay(500);

  testroundrects();
  delay(500);

  testtriangles();
  delay(500);

  mediabuttons();
  delay(500);

  Serial.println("done");
  delay(1000);
}

void loop() {
  tft.invertDisplay(true);
  delay(500);
  tft.invertDisplay(false);
  delay(500);
}

void testlines(uint16_t color) {
  tft.fillScreen(ST77XX_BLACK);
  for (int16_t x=0; x < tft.width(); x+=6) {
    tft.drawLine(0, 0, x, tft.height()-1, color);
    delay(0);
  }
  for (int16_t y=0; y < tft.height(); y+=6) {
    tft.drawLine(0, 0, tft.width()-1, y, color);
    delay(0);
  }

  tft.fillScreen(ST77XX_BLACK);
  for (int16_t x=0; x < tft.width(); x+=6) {
    tft.drawLine(tft.width()-1, 0, x, tft.height()-1, color);
    delay(0);
  }
  for (int16_t y=0; y < tft.height(); y+=6) {
    tft.drawLine(tft.width()-1, 0, 0, y, color);
    delay(0);
  }

  tft.fillScreen(ST77XX_BLACK);
  for (int16_t x=0; x < tft.width(); x+=6) {
    tft.drawLine(0, tft.height()-1, x, 0, color);
    delay(0);
  }
  for (int16_t y=0; y < tft.height(); y+=6) {
    tft.drawLine(0, tft.height()-1, tft.width()-1, y, color);
    delay(0);
  }

  tft.fillScreen(ST77XX_BLACK);
  for (int16_t x=0; x < tft.width(); x+=6) {
    tft.drawLine(tft.width()-1, tft.height()-1, x, 0, color);
    delay(0);
  }
  for (int16_t y=0; y < tft.height(); y+=6) {
    tft.drawLine(tft.width()-1, tft.height()-1, 0, y, color);
    delay(0);
  }
}

void testdrawtext(char *text, uint16_t color) {
  tft.setCursor(0, 0);
  tft.setTextColor(color);
  tft.setTextWrap(true);
  tft.print(text);
}

void testfastlines(uint16_t color1, uint16_t color2) {
  tft.fillScreen(ST77XX_BLACK);
  for (int16_t y=0; y < tft.height(); y+=5) {
    tft.drawFastHLine(0, y, tft.width(), color1);
  }
  for (int16_t x=0; x < tft.width(); x+=5) {
    tft.drawFastVLine(x, 0, tft.height(), color2);
  }
}

void testdrawrects(uint16_t color) {
  tft.fillScreen(ST77XX_BLACK);
  for (int16_t x=0; x < tft.width(); x+=6) {
    tft.drawRect(tft.width()/2 -x/2, tft.height()/2 -x/2 , x, x, color);
  }
}

void testfillrects(uint16_t color1, uint16_t color2) {
  tft.fillScreen(ST77XX_BLACK);
  for (int16_t x=tft.width()-1; x > 6; x-=6) {
    tft.fillRect(tft.width()/2 -x/2, tft.height()/2 -x/2 , x, x, color1);
    tft.drawRect(tft.width()/2 -x/2, tft.height()/2 -x/2 , x, x, color2);
  }
}

void testfillcircles(uint8_t radius, uint16_t color) {
  for (int16_t x=radius; x < tft.width(); x+=radius*2) {
    for (int16_t y=radius; y < tft.height(); y+=radius*2) {
      tft.fillCircle(x, y, radius, color);
    }
  }
}

void testdrawcircles(uint8_t radius, uint16_t color) {
  for (int16_t x=0; x < tft.width()+radius; x+=radius*2) {
    for (int16_t y=0; y < tft.height()+radius; y+=radius*2) {
      tft.drawCircle(x, y, radius, color);
    }
  }
}

void testtriangles() {
  tft.fillScreen(ST77XX_BLACK);
  uint16_t color = 0xF800;
  int t;
  int w = tft.width()/2;
  int x = tft.height()-1;
  int y = 0;
  int z = tft.width();
  for(t = 0 ; t <= 15; t++) {
    tft.drawTriangle(w, y, y, x, z, x, color);
    x-=4;
    y+=4;
    z-=4;
    color+=100;
  }
}

void testroundrects() {
  tft.fillScreen(ST77XX_BLACK);
  uint16_t color = 100;
  int i;
  int t;
  for(t = 0 ; t <= 4; t+=1) {
    int x = 0;
    int y = 0;
    int w = tft.width()-2;
    int h = tft.height()-2;
    for(i = 0 ; i <= 16; i+=1) {
      tft.drawRoundRect(x, y, w, h, 5, color);
      x+=2;
      y+=3;
      w-=4;
      h-=6;
      color+=1100;
    }
    color+=100;
  }
}

void tftPrintTest() {
  tft.setTextWrap(false);
  tft.fillScreen(ST77XX_BLACK);
  tft.setCursor(0, 30);
  tft.setTextColor(ST77XX_RED);
  tft.setTextSize(1);
  tft.println("Hello World!");
  tft.setTextColor(ST77XX_YELLOW);
  tft.setTextSize(2);
  tft.println("Hello World!");
  tft.setTextColor(ST77XX_GREEN);
  tft.setTextSize(3);
  tft.println("Hello World!");
  tft.setTextColor(ST77XX_BLUE);
  tft.setTextSize(4);
  tft.print(1234.567);
  delay(1500);
  tft.setCursor(0, 0);
  tft.fillScreen(ST77XX_BLACK);
  tft.setTextColor(ST77XX_WHITE);
  tft.setTextSize(0);
  tft.println("Hello World!");
  tft.setTextSize(1);
  tft.setTextColor(ST77XX_GREEN);
  tft.print(p, 6);
  tft.println(" Want pi?");
  tft.println(" ");
  tft.print(8675309, HEX); // print 8,675,309 out in HEX!
  tft.println(" Print HEX!");
  tft.println(" ");
  tft.setTextColor(ST77XX_WHITE);
  tft.println("Sketch has been");
  tft.println("running for: ");
  tft.setTextColor(ST77XX_MAGENTA);
  tft.print(millis() / 1000);
  tft.setTextColor(ST77XX_WHITE);
  tft.print(" seconds.");
}

void mediabuttons() {
  // play
  tft.fillScreen(ST77XX_BLACK);
  tft.fillRoundRect(25, 10, 78, 60, 8, ST77XX_WHITE);
  tft.fillTriangle(42, 20, 42, 60, 90, 40, ST77XX_RED);
  delay(500);
  // pause
  tft.fillRoundRect(25, 90, 78, 60, 8, ST77XX_WHITE);
  tft.fillRoundRect(39, 98, 20, 45, 5, ST77XX_GREEN);
  tft.fillRoundRect(69, 98, 20, 45, 5, ST77XX_GREEN);
  delay(500);
  // play color
  tft.fillTriangle(42, 20, 42, 60, 90, 40, ST77XX_BLUE);
  delay(50);
  // pause color
  tft.fillRoundRect(39, 98, 20, 45, 5, ST77XX_RED);
  tft.fillRoundRect(69, 98, 20, 45, 5, ST77XX_RED);
  // play color
  tft.fillTriangle(42, 20, 42, 60, 90, 40, ST77XX_GREEN);
}

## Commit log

2024-08-26 schematic images
2024-08-26 correction to battery holder footprint
    [BOM-MKRZero_V5.0.csv, CR1220-2.stp, MKRZero_V5.0.kicad_pcb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]
2024-08-31 add second pair of mounting holes for DIN5 midi connector socket to make compatible with different DIN5 variations
    [MKRZero_V5.0.kicad_pcb]
2024-10-02 midi connector corrections, use MG03254F-RA magnetic pogo 3pin connector
    [MG03254F-RA v1.step, MKRZero_V5.0.kicad_pcb, MKRZero_V5.0.kicad_sch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]
2024-11-02 midi still not working
    [BOM-MKRZero_V5.0.csv, EnclosureBase.stl, EnclosureLid.stl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]
2024-11-03 v1.3 hopefully midi in will work this time?
    [BOM-MKRZero_V5.0.csv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]
